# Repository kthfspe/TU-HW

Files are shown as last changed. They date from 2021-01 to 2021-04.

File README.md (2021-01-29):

# HW.template
Template for KiCAD PCB projects

## How to name your project
The kicad project name should be the name of the repo without the "-HW" part. For example EBS-HW repo should contain EBS.pro KiCAD project.  

The KiCAD project should be in the top level folder of the repo, i.e. no additional folders containing the KiCAD project should be there. To achieve that you will need to unselect an option when creating the project


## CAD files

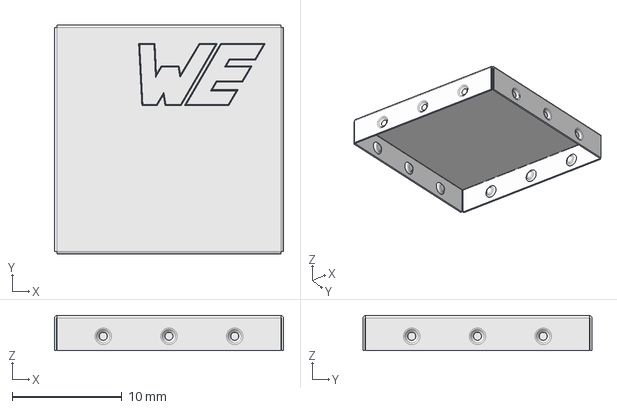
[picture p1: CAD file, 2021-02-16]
component lib/WE-SHC-36003200S (rev1).stp
20.9 x 20.9 x 3.20 mm

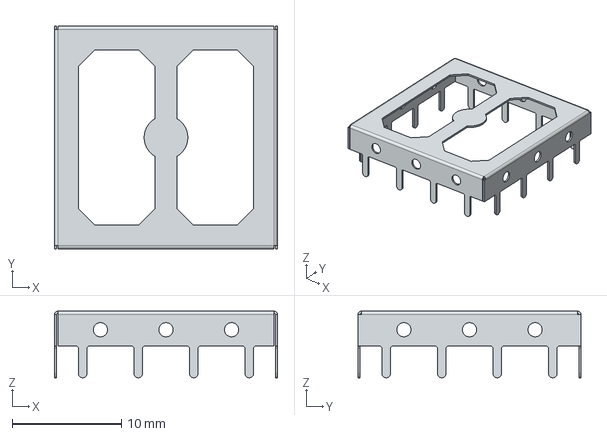
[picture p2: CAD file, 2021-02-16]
component lib/WE-SHC-36503205S (rev1).stp
20.4 x 20.4 x 6.10 mm

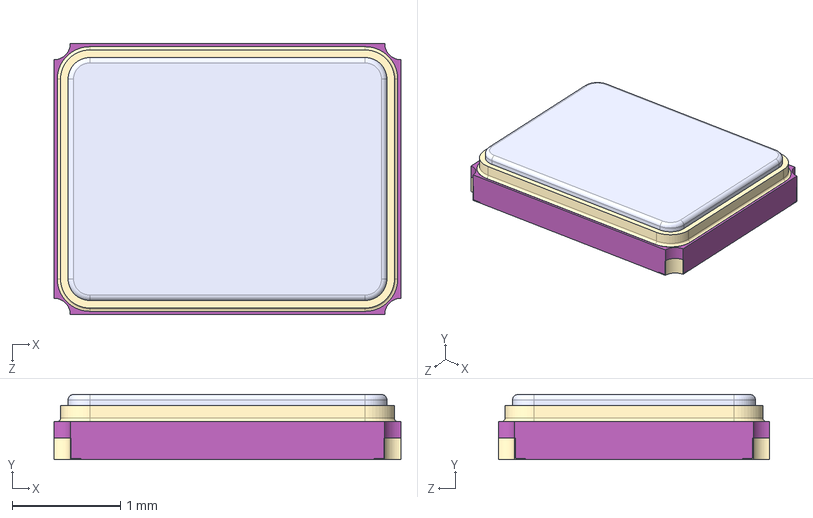
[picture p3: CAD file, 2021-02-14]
component lib/NX3225SA-40M-EXS00A-CS03880.step
3.20 x 0.6 x 2.50 mm

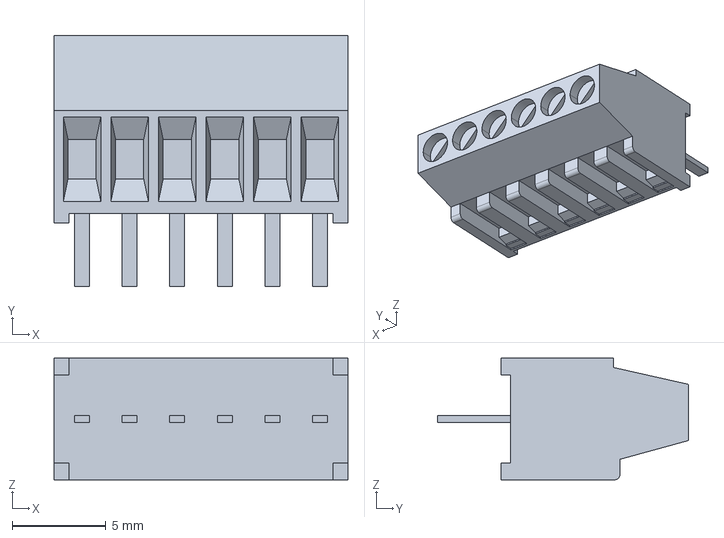
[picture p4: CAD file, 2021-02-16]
component lib/282834-6.step
15.7 x 13.4 x 6.50 mm

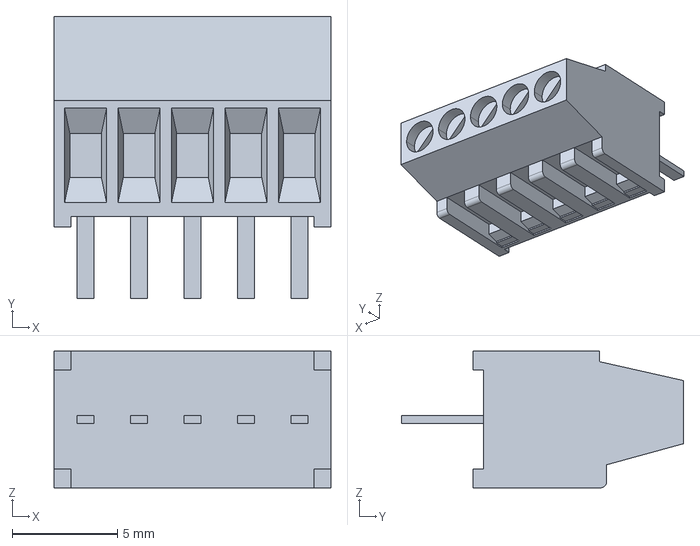
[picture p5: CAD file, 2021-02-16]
component lib/282834-5.step
13.2 x 13.4 x 6.50 mm

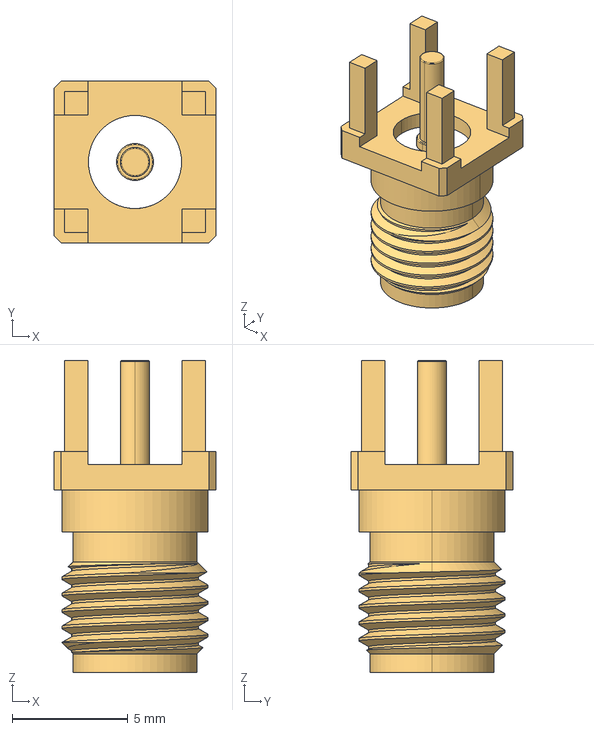
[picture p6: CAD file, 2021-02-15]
component lib/60312002114503.stp
7.00 x 7.00 x 13.5 mm

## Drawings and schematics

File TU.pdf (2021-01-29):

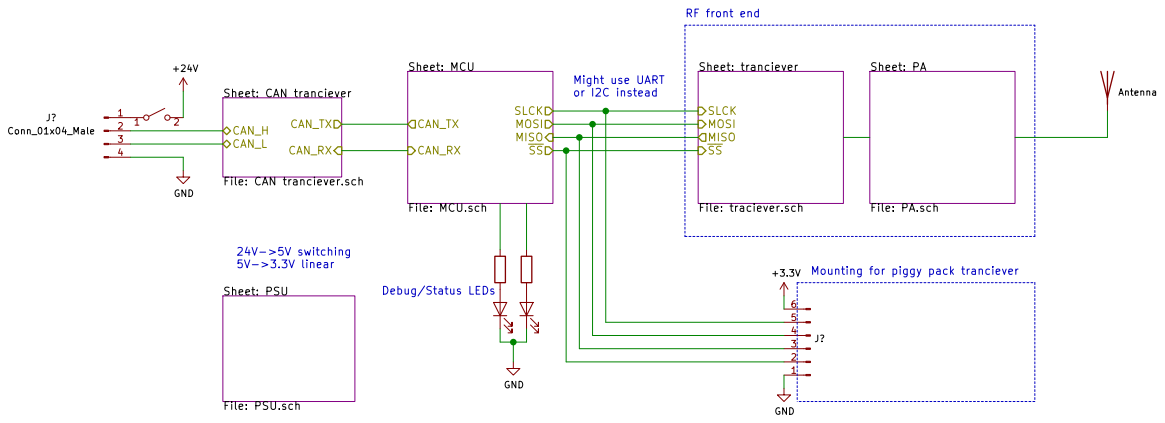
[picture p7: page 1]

File: PA.sch Sheet: MCU

Sheet: tranciever File: traciever.sch SLCK MOSI MISO

Might use UART or I2C instead

Sheet: CAN tranciever File: CAN tranciever.sch CAN_H

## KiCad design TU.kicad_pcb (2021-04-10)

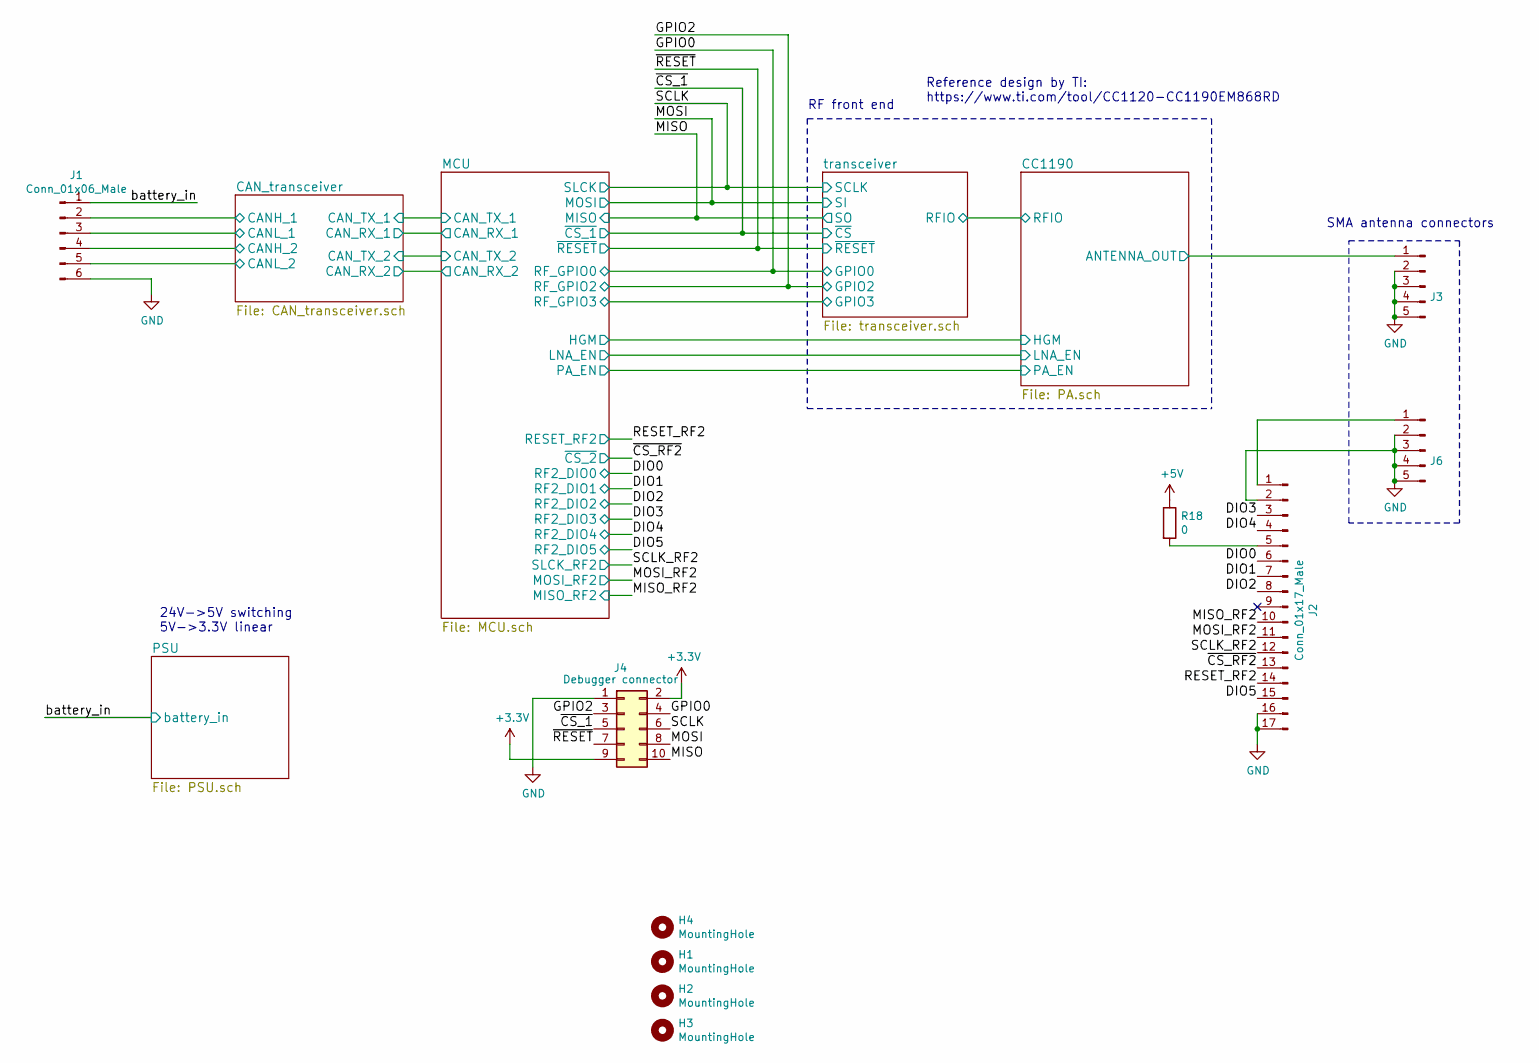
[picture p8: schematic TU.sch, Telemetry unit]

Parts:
H1, H2, H3, H4: MountingHole; MountingHole_2.5mm
J1: Conn_01x06_Male; TE_282834-6
J2: Conn_01x17_Male; RFM95PW
J3, J6: Conn_01x05_Male; Wurth_SMA_60312002114503
J4: Debugger connector; PinHeader_2x05_P2.54mm_Vertical
R18: 0; R_0603_1608Metric

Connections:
+3V3: J4.2, J4.9; also elsewhere on the board
+5V: R18.1; also elsewhere on the board
/CAN_transceiver/CANH_1: J1.2; also elsewhere on the board
/CAN_transceiver/CANH_2: J1.4; also elsewhere on the board
/CAN_transceiver/CANL_1: J1.3; also elsewhere on the board
/CAN_transceiver/CANL_2: J1.5; also elsewhere on the board
/CC1190/ANTENNA_OUT: J3.1; also elsewhere on the board
/DIO0: J2.6; also elsewhere on the board
/DIO1: J2.7; also elsewhere on the board
/DIO2: J2.8; also elsewhere on the board
/DIO3: J2.3; also elsewhere on the board
/DIO4: J2.4; also elsewhere on the board
/DIO5: J2.15; also elsewhere on the board
/GPIO0: J4.4; also elsewhere on the board
/GPIO2: J4.3; also elsewhere on the board
/MISO: J4.10; also elsewhere on the board
/MISO_RF2: J2.10; also elsewhere on the board
/MOSI: J4.8; also elsewhere on the board
/MOSI_RF2: J2.11; also elsewhere on the board
/RESET_RF2: J2.14; also elsewhere on the board
/SCLK: J4.6; also elsewhere on the board
/SCLK_RF2: J2.12; also elsewhere on the board
/battery_in: J1.1; also elsewhere on the board
/~CS_1: J4.5; also elsewhere on the board
/~CS_RF2: J2.13; also elsewhere on the board
/~RESET: J4.7; also elsewhere on the board
GND: J1.6, J2.2, J2.16, J2.17, J3.2, J3.3, J3.4, J3.5, J4.1, J6.2, J6.3, J6.4, J6.5; also elsewhere on the board
unnamed: J2.1, J6.1
unnamed: J2.5, R18.2

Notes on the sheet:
24V->5V switching 5V->3.3V linear
RF front end
SMA antenna connectors
Reference design by TI: https://www.ti.com/tool/CC1120-CC1190EM868RD

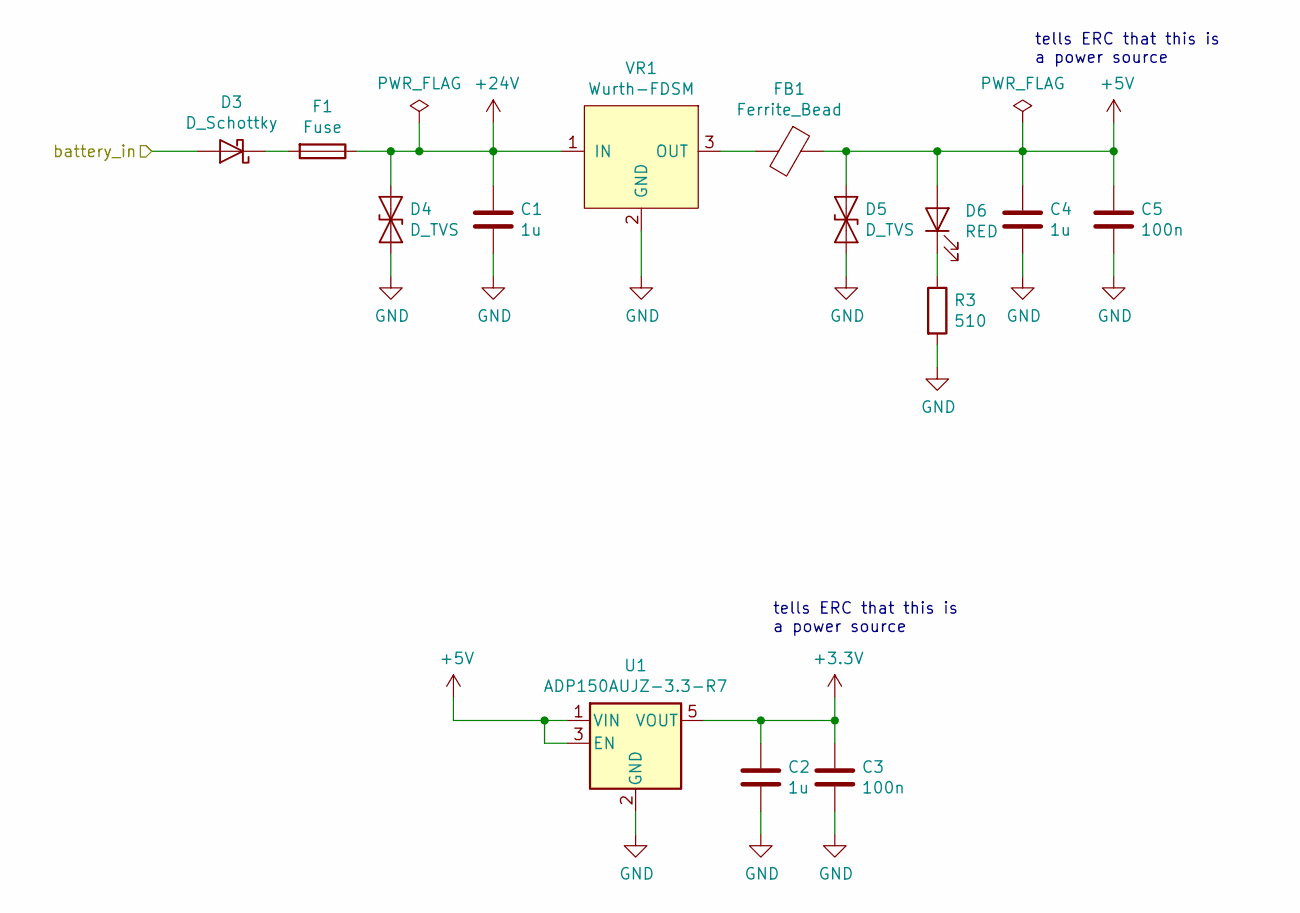
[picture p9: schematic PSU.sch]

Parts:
C1, C2: 1u; C_0805_2012Metric
C3, C5: 100n; C_0603_1608Metric
C4: 1u; C_0603_1608Metric
D3: D_Schottky; D_SOD-323
D4, D5: D_TVS; D_SOD-323
D6: RED; D_SOD-323
F1: Fuse; Fuse_0805_2012Metric
FB1: Ferrite_Bead; C_0805_2012Metric
R3: 510; R_0603_1608Metric
U1: ADP150AUJZ-3.3-R7; SOT-23-5
VR1: Wurth-FDSM

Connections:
+3V3: C2.1, C3.1, U1.5 (VOUT); also elsewhere on the board
+5V: C4.1, C5.1, D5.1 (A1), D6.2 (A), FB1.1, U1.1 (VIN), U1.3 (EN); also elsewhere on the board
+24V: C1.1, D4.1 (A1), F1.1, VR1.1 (IN)
/battery_in: D3.2 (A); also elsewhere on the board
GND: C1.2, C2.2, C3.2, C4.2, C5.2, D4.2 (A2), D5.2 (A2), R3.2, U1.2 (GND), VR1.2 (GND); also elsewhere on the board
unnamed: D3.1 (K), F1.2
unnamed: D6.1 (K), R3.1
unnamed: FB1.2, VR1.3 (OUT)

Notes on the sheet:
tells ERC that this is a power source

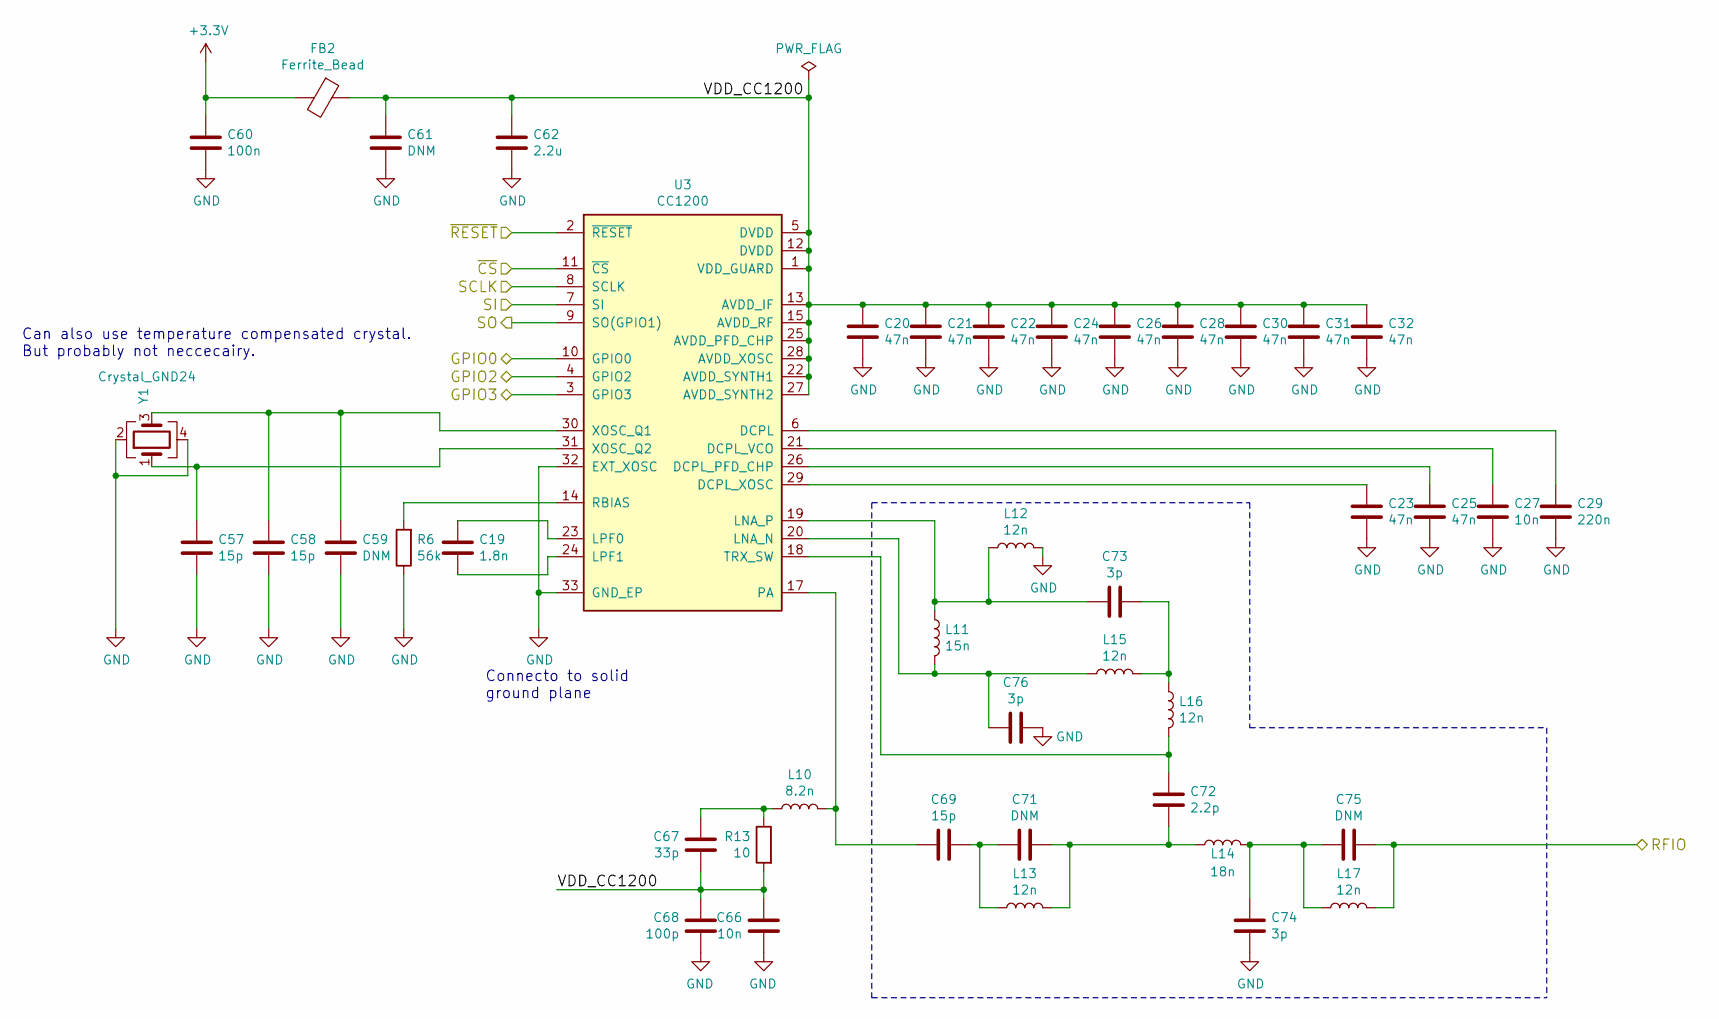
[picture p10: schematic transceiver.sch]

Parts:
C19: 1.8n; C_0603_1608Metric
C20, C21, C22, C23, C24, C25, C26, C28, C30, C31, C32: 47n; C_0603_1608Metric
C27, C66: 10n; C_0603_1608Metric
C29: 220n; C_0603_1608Metric
C57, C58, C69: 15p; C_0603_1608Metric
C59, C61, C71, C75: DNM; C_0603_1608Metric
C60: 100n; C_0603_1608Metric
C62: 2.2u; C_0603_1608Metric
C67: 33p; C_0603_1608Metric
C68: 100p; C_0603_1608Metric
C72: 2.2p; C_0603_1608Metric
C73, C74, C76: 3p; C_0603_1608Metric
FB2: Ferrite_Bead; C_0805_2012Metric
L10: 8.2n; L_0603_1608Metric
L11: 15n; L_0603_1608Metric
L12, L13, L15, L16, L17: 12n; L_0603_1608Metric
L14: 18n; L_0603_1608Metric
R6: 56k; R_0603_1608Metric
R13: 10; R_0603_1608Metric
U3: CC1200; QFN-32-1EP_5x5mm_P0.5mm_EP3.45x3.45mm
Y1: Crystal_GND24; ndk_08142018_NX3225SA

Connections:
+3V3: C60.1, FB2.2; also elsewhere on the board
/CC1190/RFIO: C75.1, L17.2; also elsewhere on the board
/GPIO0: U3.10 (GPIO0); also elsewhere on the board
/GPIO2: U3.4 (GPIO2); also elsewhere on the board
/MISO: U3.9 (SO(GPIO1)); also elsewhere on the board
/MOSI: U3.7 (SI); also elsewhere on the board
/SCLK: U3.8 (SCLK); also elsewhere on the board
/transceiver/GPIO3: U3.3 (GPIO3); also elsewhere on the board
/transceiver/VDD_CC1200: C20.1, C21.1, C22.1, C24.1, C26.1, C28.1, C30.1, C31.1, C32.1, C61.1, C62.1, C66.1, C67.2, C68.1, FB2.1, R13.2, U3.1 (VDD_GUARD), U3.5 (DVDD), U3.12 (DVDD), U3.13 (AVDD_IF), U3.15 (AVDD_RF), U3.22 (AVDD_SYNTH1), U3.25 (AVDD_PFD_CHP), U3.27 (AVDD_SYNTH2), U3.28 (AVDD_XOSC)
/~CS_1: U3.11 (~CS~); also elsewhere on the board
/~RESET: U3.2 (~RESET~); also elsewhere on the board
GND: C20.2, C21.2, C22.2, C23.2, C24.2, C25.2, C26.2, C27.2, C28.2, C29.2, C30.2, C31.2, C32.2, C57.2, C58.2, C59.2, C60.2, C61.2, C62.2, C66.2, C68.2, C74.2, C76.1, L12.2, R6.1, U3.32 (EXT_XOSC), U3.33 (GND_EP), Y1.2, Y1.4; also elsewhere on the board
unnamed: C19.1, U3.23 (LPF0)
unnamed: C19.2, U3.24 (LPF1)
unnamed: C23.1, U3.29 (DCPL_XOSC)
unnamed: C25.1, U3.26 (DCPL_PFD_CHP)
unnamed: C27.1, U3.21 (DCPL_VCO)
unnamed: C29.1, U3.6 (DCPL)
unnamed: C57.1, U3.31 (XOSC_Q2), Y1.1
unnamed: C58.1, C59.1, U3.30 (XOSC_Q1), Y1.3
unnamed: C67.1, L10.1, R13.1
unnamed: C69.1, C71.2, L13.1
unnamed: C69.2, L10.2, U3.17 (PA)
unnamed: C71.1, C72.2, L13.2, L14.1
unnamed: C72.1, L16.2, U3.18 (TRX_SW)
unnamed: C73.1, L15.2, L16.1
unnamed: C73.2, L11.1, L12.1, U3.19 (LNA_P)
unnamed: C74.1, C75.2, L14.2, L17.1
unnamed: C76.2, L11.2, L15.1, U3.20 (LNA_N)
unnamed: R6.2, U3.14 (RBIAS)

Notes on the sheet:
Connecto to solid ground plane
Can also use temperature compensated crystal. But probably not neccecairy.

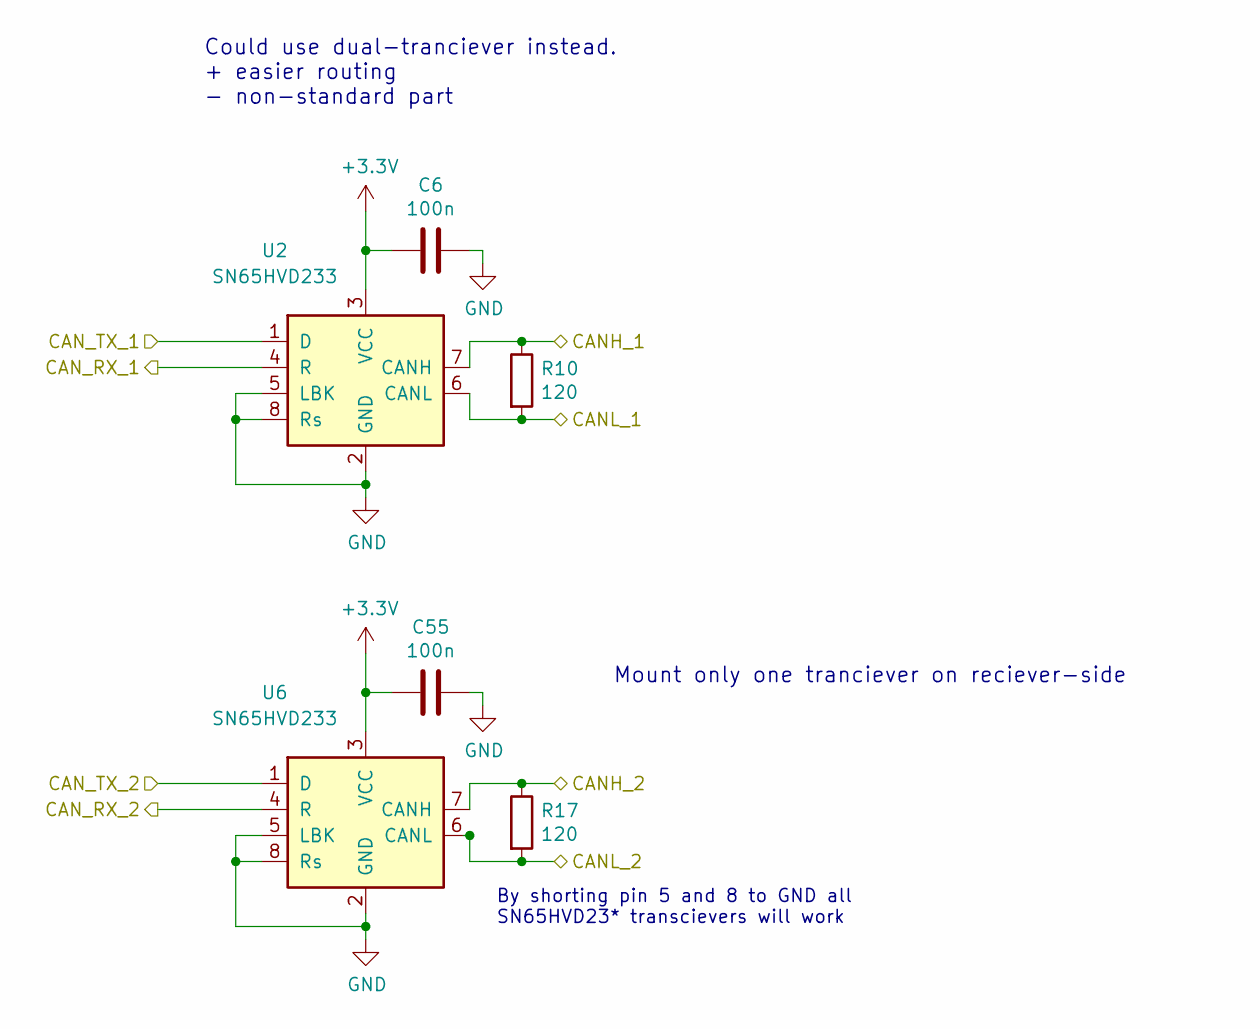
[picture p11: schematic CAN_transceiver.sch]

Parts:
C6, C55: 100n; C_0603_1608Metric
R10, R17: 120; R_0603_1608Metric
U2, U6: SN65HVD233; SOIC-8_3.9x4.9mm_P1.27mm

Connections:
+3V3: C6.2, C55.2, U2.3 (VCC), U6.3 (VCC); also elsewhere on the board
/CAN_transceiver/CANH_1: R10.1, U2.7 (CANH); also elsewhere on the board
/CAN_transceiver/CANH_2: R17.1, U6.7 (CANH); also elsewhere on the board
/CAN_transceiver/CANL_1: R10.2, U2.6 (CANL); also elsewhere on the board
/CAN_transceiver/CANL_2: R17.2, U6.6 (CANL); also elsewhere on the board
/CAN_transceiver/CAN_RX_1: U2.4 (R); also elsewhere on the board
/CAN_transceiver/CAN_RX_2: U6.4 (R); also elsewhere on the board
/CAN_transceiver/CAN_TX_1: U2.1 (D); also elsewhere on the board
/CAN_transceiver/CAN_TX_2: U6.1 (D); also elsewhere on the board
GND: C6.1, C55.1, U2.2 (GND), U2.5 (LBK), U2.8 (Rs), U6.2 (GND), U6.5 (LBK), U6.8 (Rs); also elsewhere on the board

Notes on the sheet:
By shorting pin 5 and 8 to GND all SN65HVD23* transcievers will work
Could use dual-tranciever instead. + easier routing - non-standard part
Mount only one tranciever on reciever-side

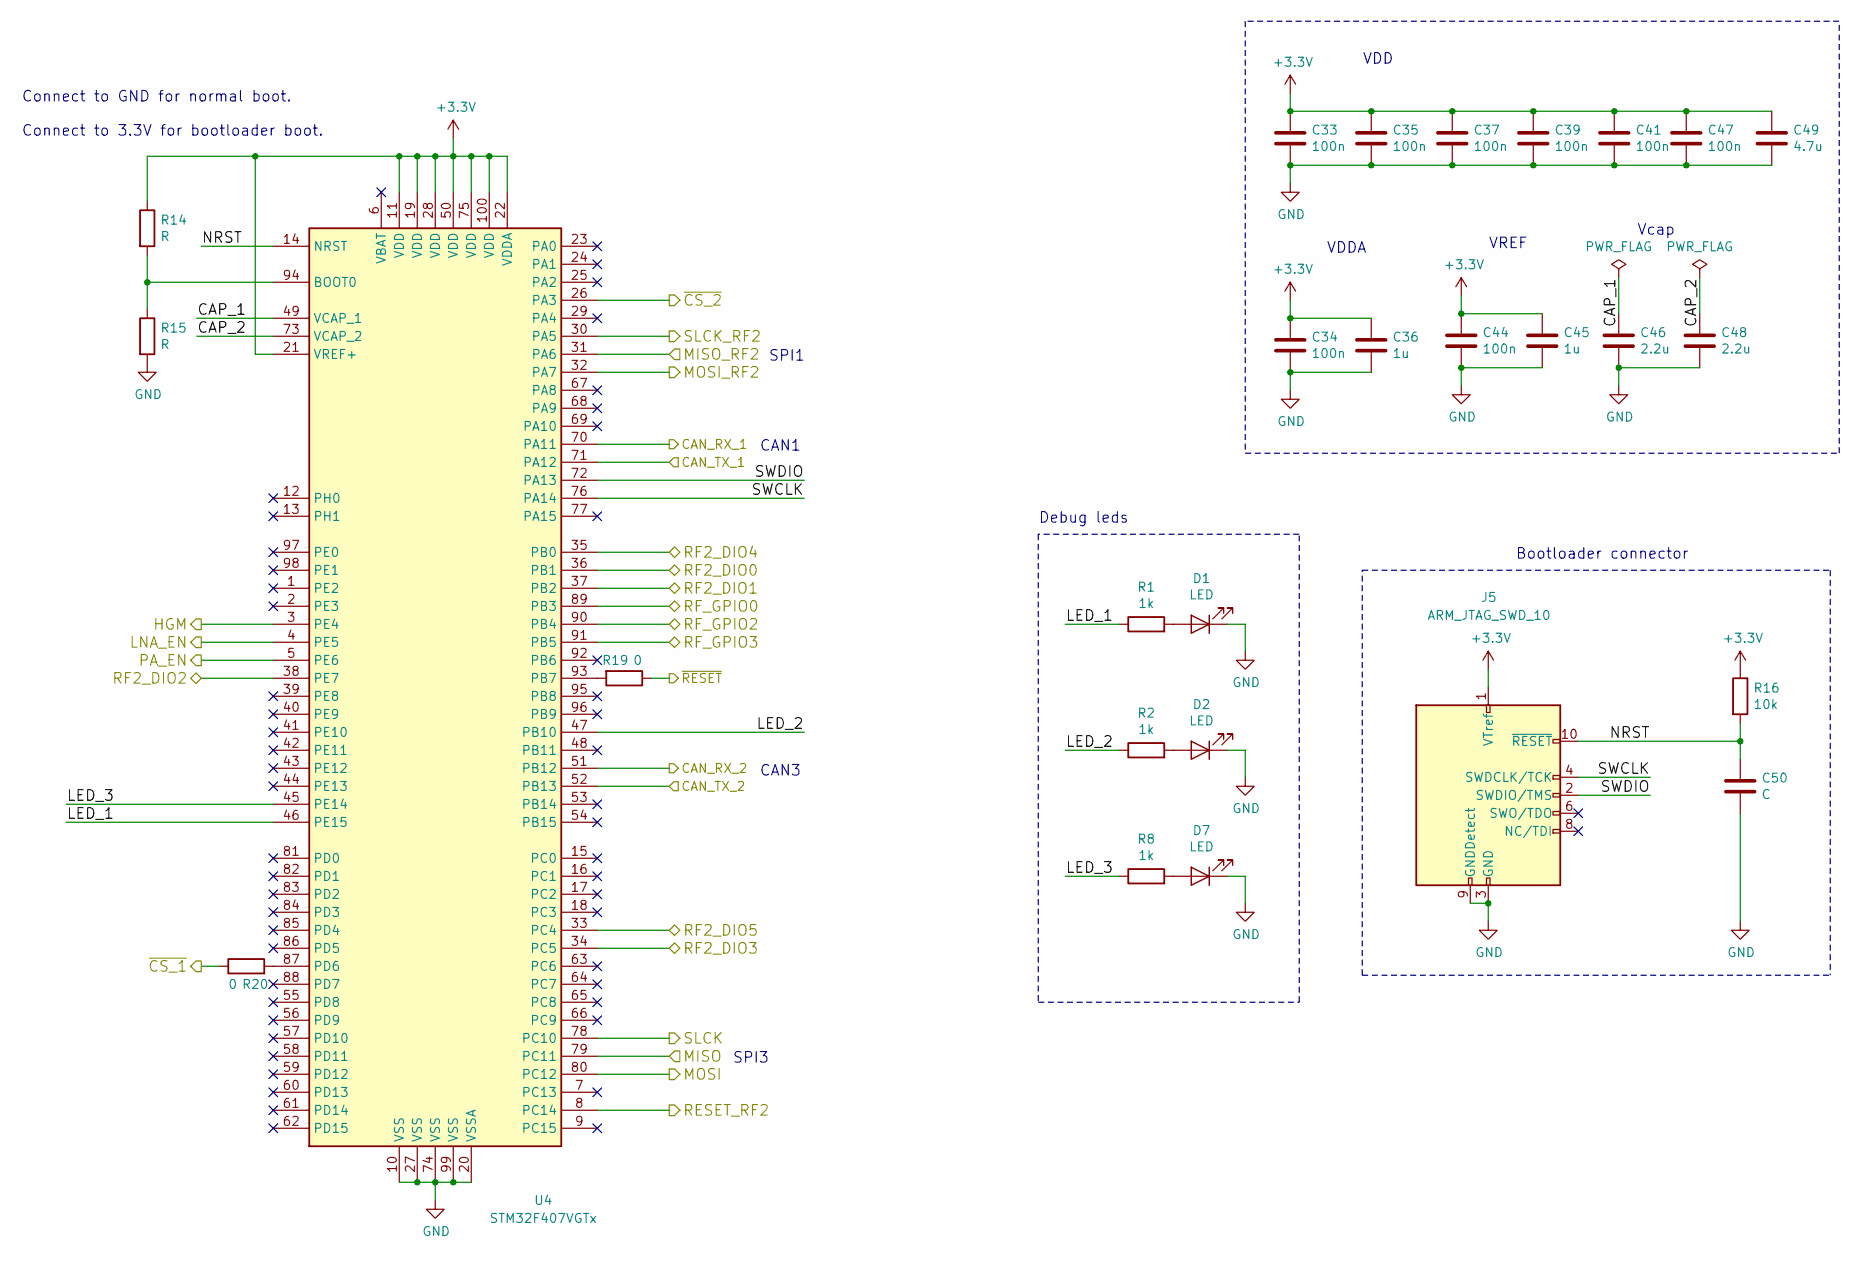
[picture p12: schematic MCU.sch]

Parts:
C33, C34, C35, C37, C39, C41, C44, C47: 100n; C_0603_1608Metric
C36, C45: 1u; C_0805_2012Metric
C46, C48: 2.2u; C_0603_1608Metric
C49: 4.7u; C_0603_1608Metric
C50: C; C_0603_1608Metric
D1, D2, D7: LED; D_0603_1608Metric
J5: ARM_JTAG_SWD_10; Atmel_ICP_connector
R1, R2, R8: 1k; R_0603_1608Metric
R14, R15: R; R_0603_1608Metric
R16: 10k; R_0603_1608Metric
R19, R20: 0; R_0603_1608Metric
U4: STM32F407VGTx; LQFP-100_14x14mm_P0.5mm

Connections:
+3V3: C33.1, C34.1, C35.1, C36.1, C37.1, C39.1, C41.1, C44.1, C45.1, C47.1, C49.1, J5.1 (VTref), R14.1, R16.1, U4.11 (VDD), U4.19 (VDD), U4.21 (VREF+), U4.22 (VDDA), U4.28 (VDD), U4.50 (VDD), U4.75 (VDD), U4.100 (VDD); also elsewhere on the board
/CAN_transceiver/CAN_RX_1: U4.70 (PA11); also elsewhere on the board
/CAN_transceiver/CAN_RX_2: U4.51 (PB12); also elsewhere on the board
/CAN_transceiver/CAN_TX_1: U4.71 (PA12); also elsewhere on the board
/CAN_transceiver/CAN_TX_2: U4.52 (PB13); also elsewhere on the board
/CC1190/HGM: U4.3 (PE4); also elsewhere on the board
/CC1190/LNA_EN: U4.4 (PE5); also elsewhere on the board
/CC1190/PA_EN: U4.5 (PE6); also elsewhere on the board
/DIO0: U4.36 (PB1); also elsewhere on the board
/DIO1: U4.37 (PB2); also elsewhere on the board
/DIO2: U4.38 (PE7); also elsewhere on the board
/DIO3: U4.34 (PC5); also elsewhere on the board
/DIO4: U4.35 (PB0); also elsewhere on the board
/DIO5: U4.33 (PC4); also elsewhere on the board
/GPIO0: U4.89 (PB3); also elsewhere on the board
/GPIO2: U4.90 (PB4); also elsewhere on the board
/MCU/CAP_1: C46.1, U4.49 (VCAP_1)
/MCU/CAP_2: C48.1, U4.73 (VCAP_2)
/MCU/LED_1: R1.1, U4.46 (PE15)
/MCU/LED_2: R2.1, U4.47 (PB10)
/MCU/LED_3: R8.1, U4.45 (PE14)
/MCU/NRST: C50.1, J5.10 (~RESET~), R16.2, U4.14 (NRST)
/MCU/SWCLK: J5.4 (SWDCLK/TCK), U4.76 (PA14)
/MCU/SWDIO: J5.2 (SWDIO/TMS), U4.72 (PA13)
/MISO: U4.79 (PC11); also elsewhere on the board
/MISO_RF2: U4.31 (PA6); also elsewhere on the board
/MOSI: U4.80 (PC12); also elsewhere on the board
/MOSI_RF2: U4.32 (PA7); also elsewhere on the board
/RESET_RF2: U4.8 (PC14); also elsewhere on the board
/SCLK: U4.78 (PC10); also elsewhere on the board
/SCLK_RF2: U4.30 (PA5); also elsewhere on the board
/transceiver/GPIO3: U4.91 (PB5); also elsewhere on the board
/~CS_1: R20.1; also elsewhere on the board
/~CS_RF2: U4.26 (PA3); also elsewhere on the board
/~RESET: R19.1; also elsewhere on the board
GND: C33.2, C34.2, C35.2, C36.2, C37.2, C39.2, C41.2, C44.2, C45.2, C46.2, C47.2, C48.2, C49.2, C50.2, D1.1 (K), D2.1 (K), D7.1 (K), J5.3 (GND), J5.5 (GND), J5.9 (GNDDetect), R15.2, U4.10 (VSS), U4.20 (VSSA), U4.27 (VSS), U4.74 (VSS), U4.99 (VSS); also elsewhere on the board
unnamed: D1.2 (A), R1.2
unnamed: D2.2 (A), R2.2
unnamed: D7.2 (A), R8.2
unnamed: R14.2, R15.1, U4.94 (BOOT0)
unnamed: R19.2, U4.93 (PB7)
unnamed: R20.2, U4.87 (PD6)

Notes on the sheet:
VDD
VDDA
Bootloader connector
Debug leds
CAN1
CAN3
SPI1
VREF
Vcap
Connect to GND for normal boot. Connect to 3.3V for bootloader boot.
SPI3

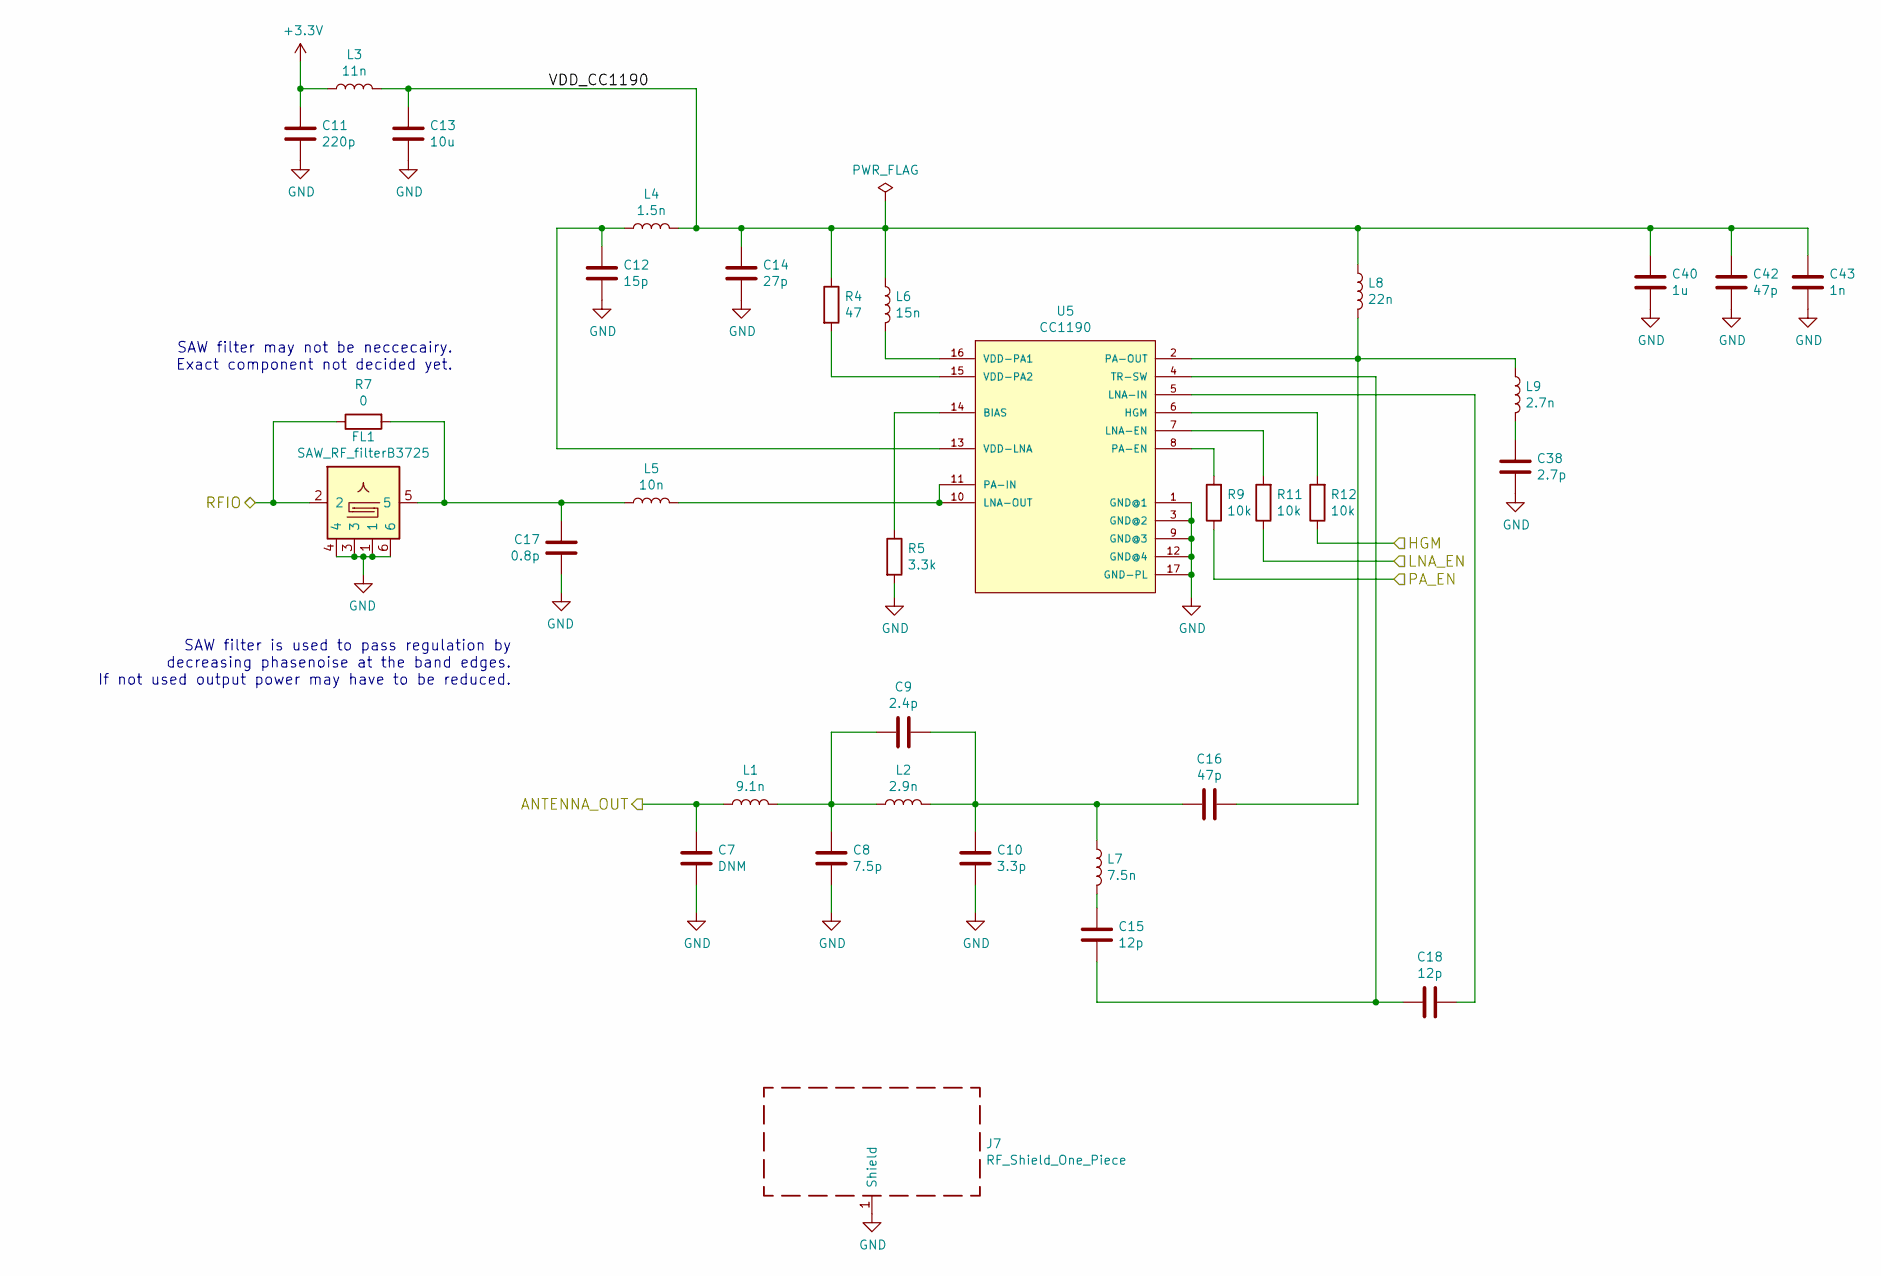
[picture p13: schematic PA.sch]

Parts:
C7: DNM; C_0603_1608Metric
C8: 7.5p; C_0603_1608Metric
C9: 2.4p; C_0603_1608Metric
C10: 3.3p; C_0603_1608Metric
C11: 220p; C_0603_1608Metric
C12: 15p; C_0603_1608Metric
C13: 10u; C_0603_1608Metric
C14: 27p; C_0603_1608Metric
C15, C18: 12p; C_0603_1608Metric
C16, C42: 47p; C_0603_1608Metric
C17: 0.8p; C_0603_1608Metric
C38: 2.7p; C_0603_1608Metric
C40: 1u; C_0603_1608Metric
C43: 1n; C_0603_1608Metric
FL1: SAW_RF_filterB3725; SON120P300X300X110-6N
J7: RF_Shield_One_Piece; WE_shield_20x20_36503205S
L1: 9.1n; L_0603_1608Metric
L2: 2.9n; L_0603_1608Metric
L3: 11n; L_0603_1608Metric
L4: 1.5n; L_0603_1608Metric
L5: 10n; L_0603_1608Metric
L6: 15n; L_0603_1608Metric
L7: 7.5n; L_0603_1608Metric
L8: 22n; L_0603_1608Metric
L9: 2.7n; L_0603_1608Metric
R4: 47; R_0603_1608Metric
R5: 3.3k; R_0603_1608Metric
R7: 0; R_0603_1608Metric
R9, R11, R12: 10k; R_0603_1608Metric
U5: CC1190; QFN-16-1EP_4x4mm_P0.65mm_EP2.15x2.15mm

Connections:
+3V3: C11.1, L3.1; also elsewhere on the board
/CC1190/ANTENNA_OUT: C7.1, L1.1; also elsewhere on the board
/CC1190/HGM: R9.1; also elsewhere on the board
/CC1190/LNA_EN: R11.1; also elsewhere on the board
/CC1190/PA_EN: R12.1; also elsewhere on the board
/CC1190/RFIO: FL1.2, R7.1; also elsewhere on the board
/CC1190/VDD_CC1190: C13.1, C14.1, C40.1, C42.1, C43.1, L3.2, L4.2, L6.1, L8.1, R4.1
GND: C7.2, C8.2, C10.2, C11.2, C12.2, C13.2, C14.2, C17.2, C38.2, C40.2, C42.2, C43.2, FL1.1, FL1.3, FL1.4, FL1.6, J7.1, R5.2, U5.1 (GND@1), U5.3 (GND@2), U5.9 (GND@3), U5.12 (GND@4), U5.17 (GND-PL); also elsewhere on the board
unnamed: C8.1, C9.2, L1.2, L2.1
unnamed: C9.1, C10.1, C16.2, L2.2, L7.1
unnamed: C12.1, L4.1, U5.13 (VDD-LNA)
unnamed: C15.1, L7.2
unnamed: C15.2, C18.2, U5.4 (TR-SW)
unnamed: C16.1, L8.2, L9.1, U5.2 (PA-OUT)
unnamed: C17.1, FL1.5, L5.1, R7.2
unnamed: C18.1, U5.5 (LNA-IN)
unnamed: C38.1, L9.2
unnamed: L5.2, U5.10 (LNA-OUT), U5.11 (PA-IN)
unnamed: L6.2, U5.16 (VDD-PA1)
unnamed: R4.2, U5.15 (VDD-PA2)
unnamed: R5.1, U5.14 (BIAS)
unnamed: R9.2, U5.8 (PA-EN)
unnamed: R11.2, U5.7 (LNA-EN)
unnamed: R12.2, U5.6 (HGM)

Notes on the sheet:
SAW filter may not be neccecairy. Exact component not decided yet.
SAW filter is used to pass regulation by decreasing phasenoise at the band edges. If not used output power may have to be reduced.

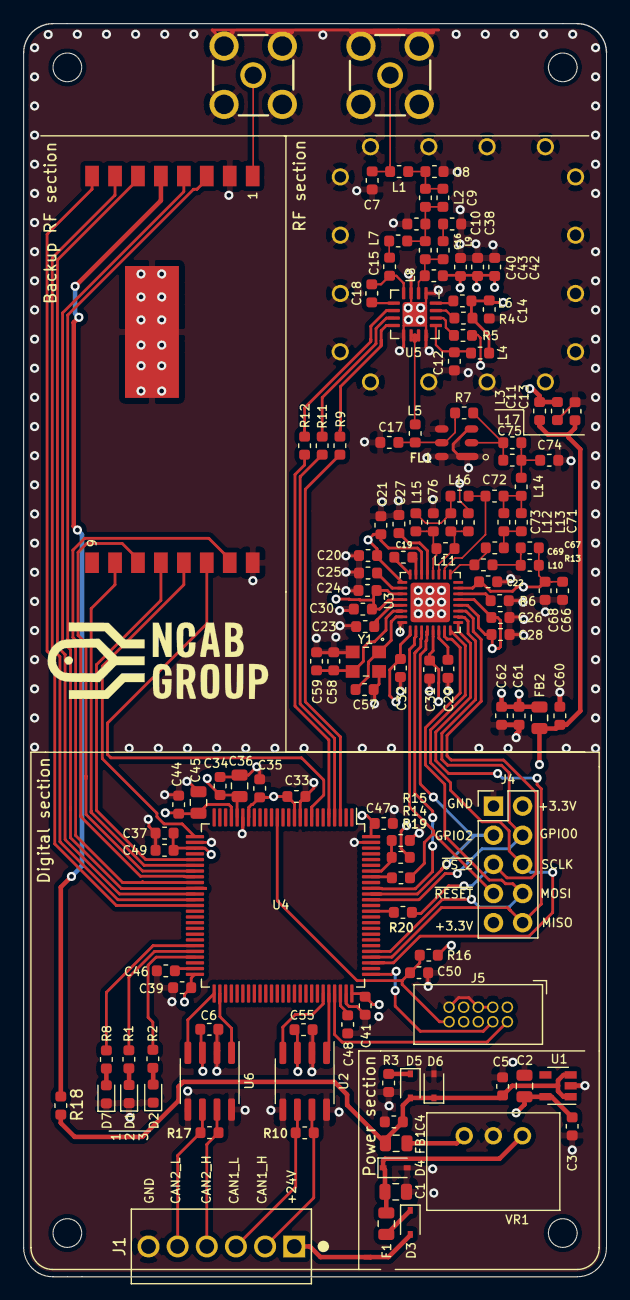
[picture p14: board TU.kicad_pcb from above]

Board: 4 copper layers, 50.8 x 109.2 mm, 134 parts (0 on the bottom side), 92 nets.

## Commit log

2021-01-29 Created KiCad project
    [TU.kicad_pcb, TU.sch]
2021-01-29 Set up rough system block diagram
    [CAN tranciever.sch, MCU.sch, PA.sch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]
2021-01-29 Imported CAN and PSU blocks from infrastructure rep
    [CAN tranciever.sch, MCU.sch, PSU.sch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]
2021-01-29 Fixed weird hierarchical sheets
    [CAN tranciever.sch, CAN_transceiver.sch, PSU.sch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]
2021-02-01 Added CC1190 library
    [PA.sch, transceiver.sch]
2021-02-02 Added cc1190 reference design
    also changed cc1190 symbol
    [PA.sch, TU.sch]
2021-02-02 Started work on CC1200
    might not be actual final tranciever
    [MCU.sch, PA.sch, TU.sch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]
2021-02-04 Started work on MCU
    [CAN_transceiver.sch, MCU.sch, TU.sch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]
2021-02-04 More work on tranciever and PA
    [MCU.sch, PA.sch, PSU.sch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]
2021-02-04 quick fix
    [TU.sch]
2021-02-04 Added mount for RFM98/95
    [PA.sch, TU.sch, transceiver.sch]
2021-02-04 Added component values for tranciever and PA
    [PA.sch, TU.sch, transceiver.sch]
2021-02-10 Small changes to schematic
    [CAN_transceiver.sch, MCU.sch, PA.sch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]
2021-02-10 Corrected some component values
    [transceiver.sch]
2021-02-11 Added MCU config pins
    [CAN_transceiver.sch, MCU.sch, TU.sch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]
2021-02-12 Changes to PA layout
    [CAN_transceiver.sch, MCU.sch, PA.sch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]
2021-02-13 Changed to F4 MCU
    [MCU.sch, PA.sch]
2021-02-13 Even more small routing changes
    [MCU.sch]
2021-02-13 Revert "Even more small routing changes"
    This reverts commit 45de819c3fcd9a95750db64bc32d705dea6ff935.
    [MCU.sch]
2021-02-14 Lots of work on routing and pcb layout
    [CAN_transceiver.sch, MCU.sch, NX3225SA-40M-EXS00A-CS03880.step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]
2021-02-15 More routing changes
    [60312002114503.stp, MCU.sch, PA.sch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]
2021-02-16 Added edge cuts and silk screen comments
    [MCU.sch, TU.kicad_pcb, TU.sch]
2021-02-16 Added mounting holes and terminal block
    [282834-5.step, 282834-6.step, MCU.sch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]
2021-02-16 Small tweaks
    [TU.kicad_pcb]
2021-02-16 Routed power for RF
    [MCU.sch, PA.sch, TU.kicad_pcb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]
2021-02-16 Feedback from peer review
    [PA.sch, TU.kicad_pcb]
2021-02-16 Added heatpad vias for extra rf module.
    [TU.kicad_pcb]
2021-02-16 Made sections clearer and cleaned up silkscreen.
    [CAN_transceiver.sch, TU.kicad_pcb, TU.sch]
2021-02-16 Added PA shield
    [PA.sch, TU.kicad_pcb, TU.sch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]
2021-02-16 preliminairy routing of 50 ohm traces
    [TU.kicad_pcb]
2021-02-17 Added guard ring and cleaned up silkscreen
    [MCU.sch, PA.sch, TU.kicad_pcb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]
2021-02-17 Changed track width for 50 ohm traces
    [TU.kicad_pcb]
2021-02-17 Small changes to routing
    [TU.kicad_pcb]
2021-02-17 Fixed (most) pwr flag issues
    [MCU.sch, PA.sch, PSU.sch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]
2021-02-17 Added ncab logo
    [TU.kicad_pcb]
2021-04-10 Fixed HGM/PA mixup
    [MCU.sch, PA.sch, TU.kicad_pcb]
